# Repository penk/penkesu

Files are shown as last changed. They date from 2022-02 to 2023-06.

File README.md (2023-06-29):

# Penkesu Computer - A Homebrew Retro-style Handheld PC



The Penkēsu (Japanese: `ペンケース`) is a retro-style handheld device powered by a Raspberry Pi Zero 2 W, a 7.9 inch widescreen display (1280 x 400 resolution), and a 48-key ortholinear mechanical keyboard. 

## The Design

The enclosure of the Penkesu Computer is designed around the display and keyboard to ensure (relatively) compact physical dimensions.

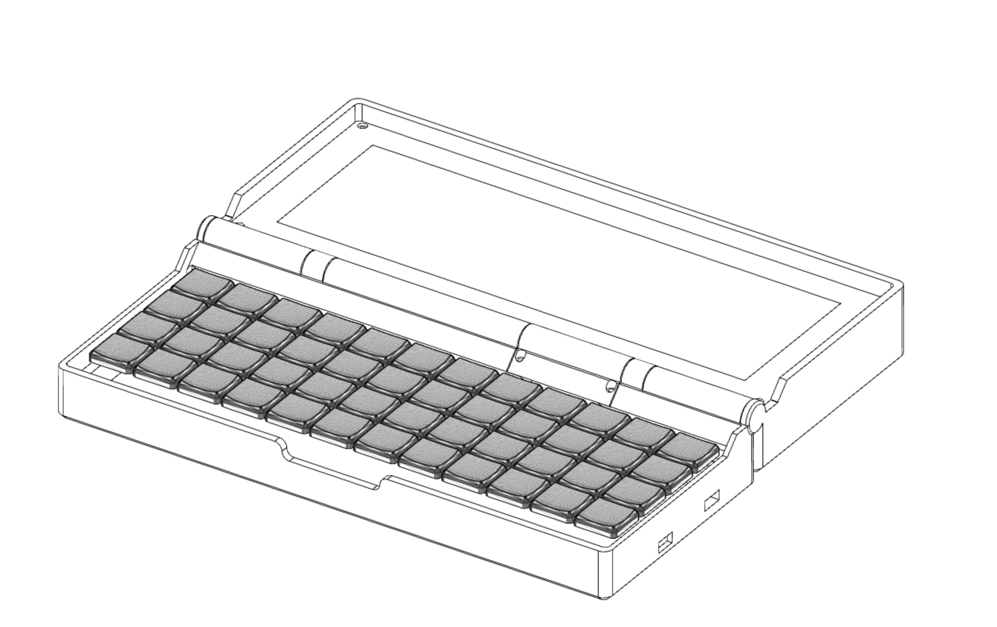
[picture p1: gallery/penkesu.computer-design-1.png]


Repurposed Gameboy Advance SP hinges and a ribbon cable for HDMI are used to keep the hinge design thin, yet they hold the weight of the display so that it won't tip over.

Electronics are intentionally kept minimal (3 internal components) and most of the parts are either 3D printable or available as off-the-shelf products. 

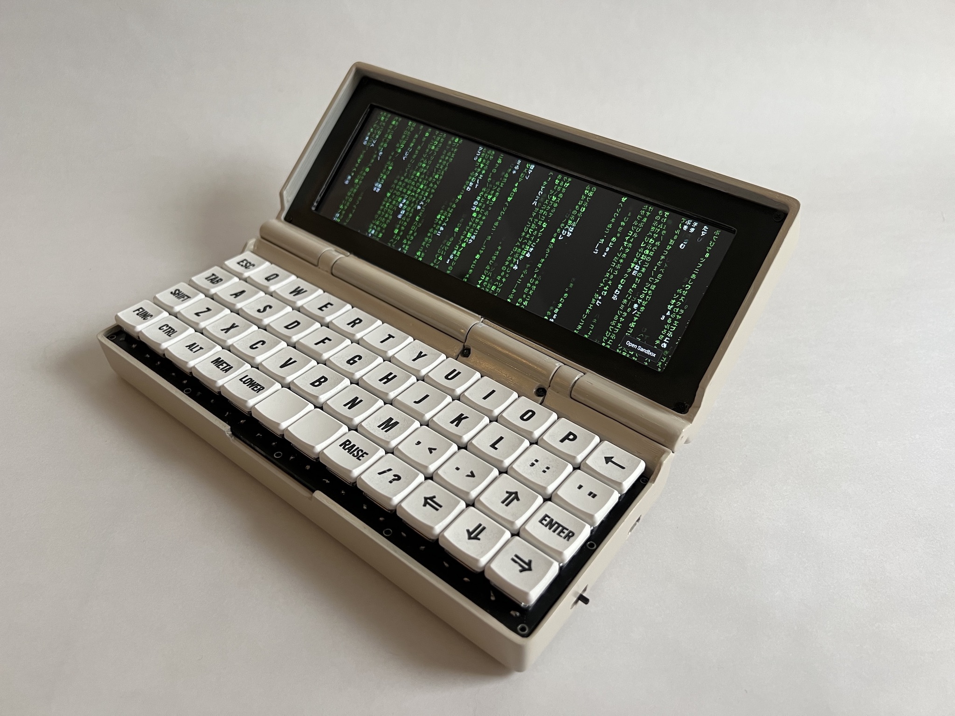
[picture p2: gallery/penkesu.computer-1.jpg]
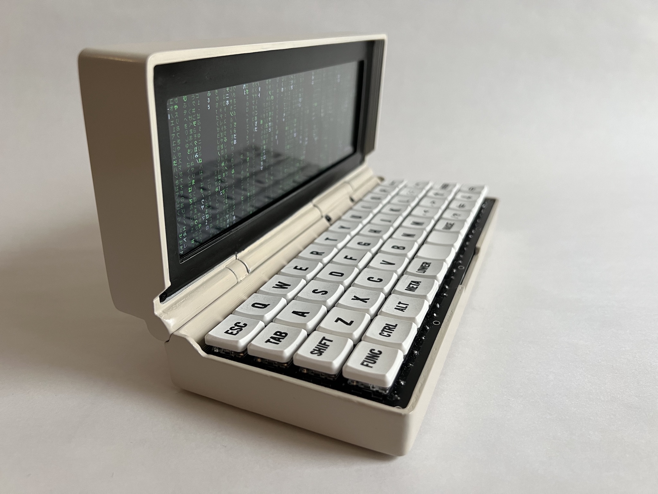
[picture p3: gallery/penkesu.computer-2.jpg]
|  |  | 
|---|---|
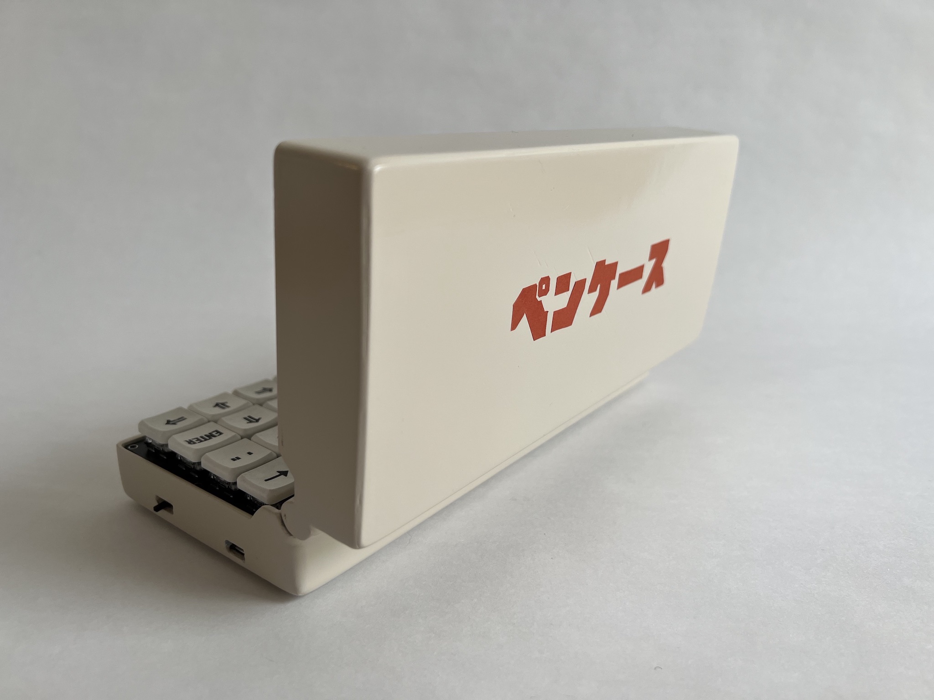
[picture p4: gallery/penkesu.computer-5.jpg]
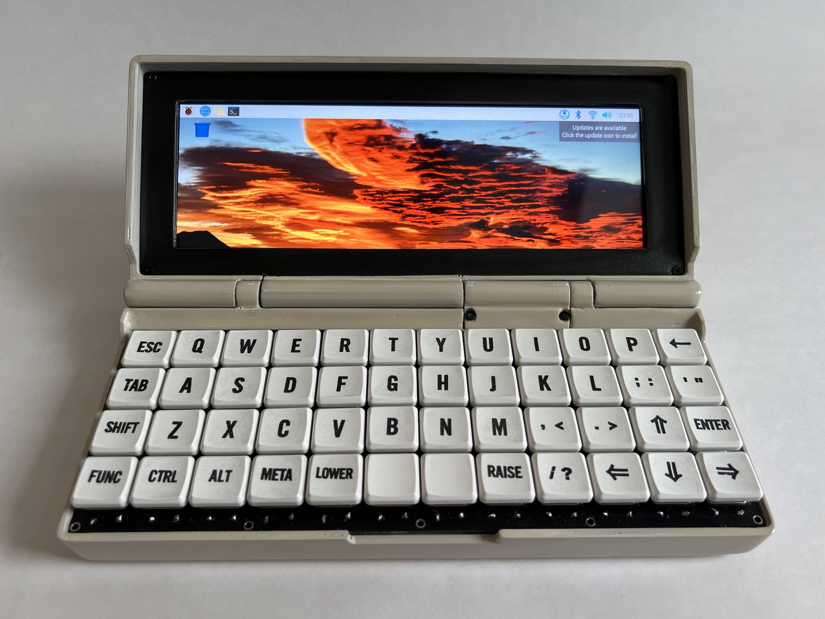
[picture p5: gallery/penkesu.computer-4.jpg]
|  |  | 
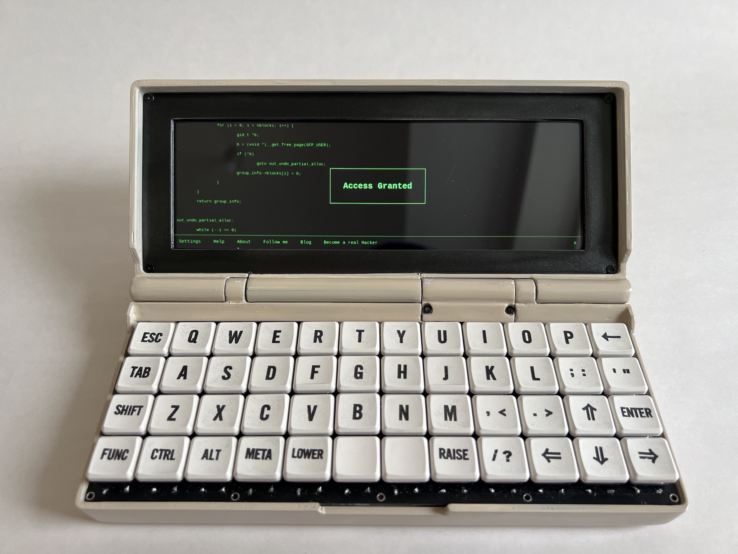
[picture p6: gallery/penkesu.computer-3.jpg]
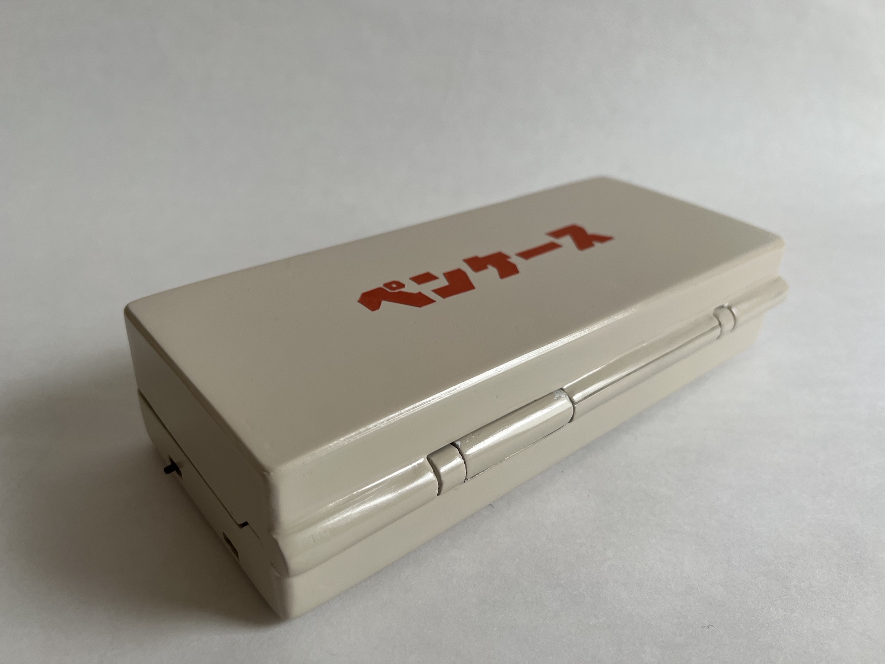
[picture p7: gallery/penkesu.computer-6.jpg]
|  |  | 

See also: the keyboard [sound test video](https://twitter.com/penk/status/1492715339997925376).

## Open Source Hardware 

Ever since the [CutiePi tablet](https://cutiepi.io) was successfully funded and started shipping, I felt the need to work on a new project; something that I didn't need to worry too much about (ie: commercial viability), and to remind myself why I started tinkering. A "rebound" project, so to speak. 

And since there are no immediate plans on selling kits or making the Penkesu Computer mass producible, I wanted to publish all the designs and plans so there's enough information for anyone interested in making one. 

## Bill of Materials 



- Display 
    - Waveshare [7.9inch Capacitive Touch Screen](https://www.waveshare.com/7.9inch-HDMI-LCD.htm)
    - Adafruit DIY HDMI Cable Parts - [Right Angle adapter](https://www.adafruit.com/product/3550), [Mini HDMI adapter](https://www.adafruit.com/product/3552), and [20cm Ribbon Cable](https://www.adafruit.com/product/3561)
- Case 
    - Gameboy Advance SP [Replacement Hinges](https://amazon.com/dp/B00YCEOXIK)
    - 3D printed parts ([STL files](stl) and [STEP file](step)) 
    - M2x6mm screws x 6 (8 if intending to secure the keyboard to the bottom tray. See part 2 below for more info.)
    - M2x6mm threaded heat-set inserts x 6 (8 if intending to secure the keyboard to the bottom tray. See part 2 below for more info.)
- Electronics 
    - Raspberry Pi [Zero 2 W](https://www.raspberrypi.com/products/raspberry-pi-zero-2-w/)
    - 3.7V 606090 (or similar size) [Li-Po battery](https://www.aliexpress.com/wholesale?SearchText=606090+battery)
    - Adafruit [PowerBoost 1000C](https://www.adafruit.com/product/2465)
- Keyboard 
    - Kailh Low Profile [Choc v1](https://www.adafruit.com/product/5114) Switches x 48
    - MBK Choc Low Profile Keycaps x 48
    - 1N4148 Diode x 48 
    - Arduino Pro Micro x 1
    - PCB x 1 ([gerber file](https://github.com/larrbo/odd-rocket/blob/master/koda/koda_no%20silk.zip) and [QMK firmware](firmware))

Links are **not** affiliate links, and only provided as references. 

## Notes on the Keyboard

About the keyboard: 

- The keyboard is called `Koda`, which is originally designed by [larrbo](https://github.com/larrbo/odd-rocket/) and released under Creative Commons BY-NC-SA 4.0 License. I've tweaked the layout so that it better fits my needs and looks closer to the `Planck`. More on this below.
- If one wishes to use a different 40% keyboard for the build, it can be done by editing the STEP file and adjusting the compartment size in the chassis.
- A thin metal sheet was [glued to the base](https://twitter.com/penk/status/1489810591628034048) as the counterweight, your mileage may vary depending on how you like the weight distribution

For the keycaps: 

- The legends on keycaps were [printed with a laser engraver](https://twitter.com/penk/status/1477140916565843968), which I used [black dip powder for nails](https://twitter.com/penk/status/1475763655212138499) as pigment. 
- More information about this method can be found with keywords [laser dye-sub keycaps](https://www.youtube.com/watch?v=qqAspFVRZNk) 
- There are custom printing services for keycaps e.g. [yushakobo.jp](https://shop.yushakobo.jp/collections/services/products/keycap-laser-marking) if one does not have access to a laser engraver.

Keyboard Layout: 



The lower key activates a layer that primarily has number keys from ` to 1 - 0 across the top row (excluding the top right key, which is the backspace key in all layers). 
The raise key activates a layer that has the shifted version of all of the numeral keys from the lower layer. As well as function keys using the tab,a,s,d,f,g and shift,z,x,c,v,b keys for F1-F6 and F7-F12 accordingly. 
Pushing func key down and holding it activates a mouse layer. The mouse layer uses an accelerated mode but allows one to temporarily activate the constant mode using an additional key. As you  might have guessed, when using the accelerated mode the speed of the cursor is initially slow but over time increases in speed. This mode is active as soon as mouse mode is entered. (by holding down the func key) Your w,a,s,d keys are you cursor movement keys. Your left, right, and middle mouse buttons are j,k, and l respectively. Your scroll wheel uses the t,f,g,h keys. Finally mouse cursor speed can be toggled by tapping or by holding. If tapped the keys change the speed of acceleration. If the keys are held they will activate constant mode at the equivalent mousing speed.  There are 3 overall speeds: 0, 1, and 2, with 0 being the slowest and most precise, and 2 being the fasted and most inaccurate. You access speed 0 using the v key. Speed 1 using the b key. And the fastest speed (2) using the n key. 

## The Assembly 

1. Glue the two hinges to the chassis (my 3D printer is not accurate enough to print a functional hinge lock, so I simply glued them with 5 minute epoxy.) You want to make sure that the hinge is able to still turn after the epoxy has set. 

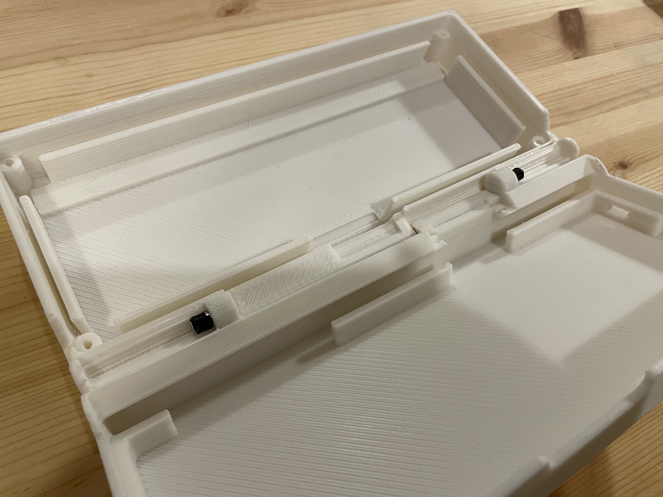
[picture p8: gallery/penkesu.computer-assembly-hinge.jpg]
  

2. Add heat-set threaded inserts (M2x6mm) to the 4 corners of screen bezel, and 2 to the hinge cover. You may also use heat insert at the front corners of the keyboard tray. Just note that placing these inserts are very difficult, and not entirely necessary. For ease of access you may wish to not use them at all. 

3. Wrap the ribbon cable twice and pull it out through the hinge cover. If you use a toothpick, it might make it easier to ensure you do this cleanly through the display cover. 

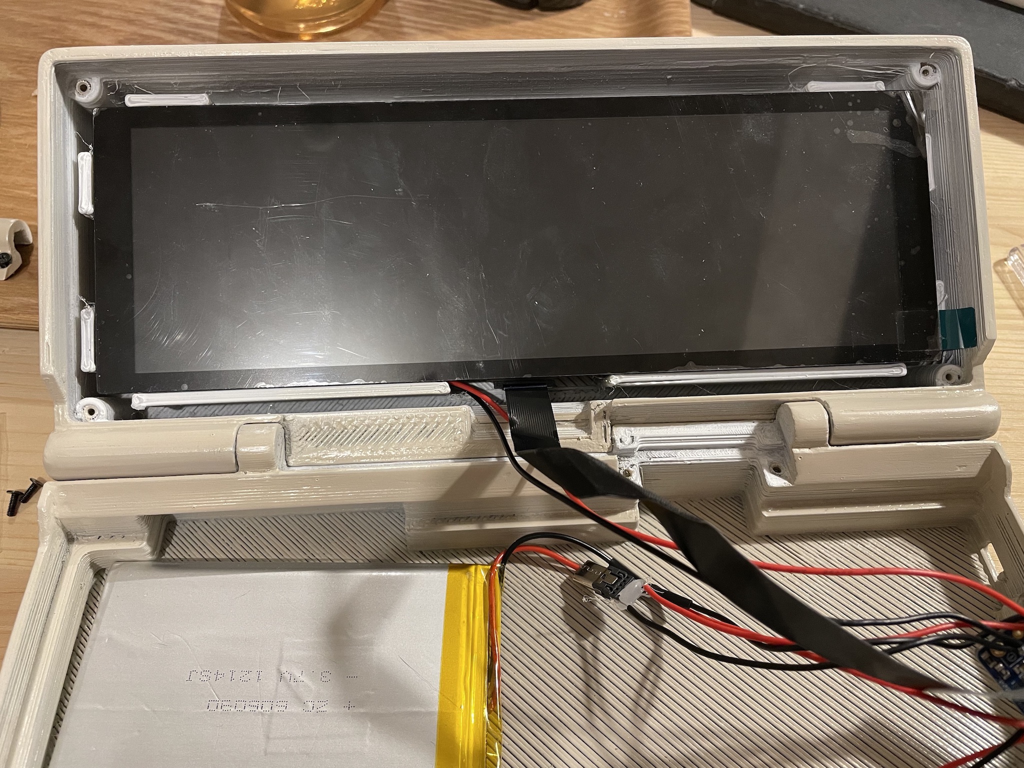
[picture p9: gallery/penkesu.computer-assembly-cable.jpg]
  

4. Wiring: 

    | Component | Pin | 
    |-----------|--------|
    | battery positive | PowerBoost `Bat` pin |
    | battery negative | PowerBoost `GND` pin | 
    | switch 1 pin | PowerBoost `GND` pin | 
    | switch 2 pin | PowerBoost `EN` pin | 
    | PowerBoost `5V OUT` | display and Pi Zero's `VCC` | 
    | PowerBoost `GND` | display and Pi Zero's `GND` |

     

5. Connect the keyboard's micro USB and the display cable into the mini HDMI port of the Pi Zero 2 W; inset the micro SD card into the Pi Zero 2 W. 
6. Fasten all components with M2x6mm screws. 

If you made it this far, you are welcome to check out my other project, [the CutiePi tablet](http://cutiepi.io), which is also 100% open source hardware! :-)

## Copyright and License

Copyright (c) 2022 Penk Chen. All rights reserved.

All files are licensed under MIT license, see the [LICENSE](LICENSE) for more information.

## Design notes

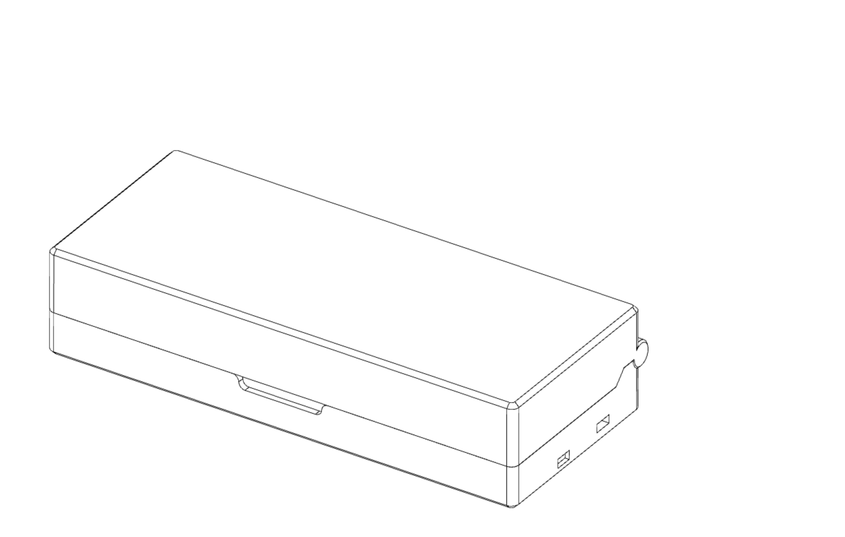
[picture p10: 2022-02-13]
gallery/penkesu.computer-design-2.png

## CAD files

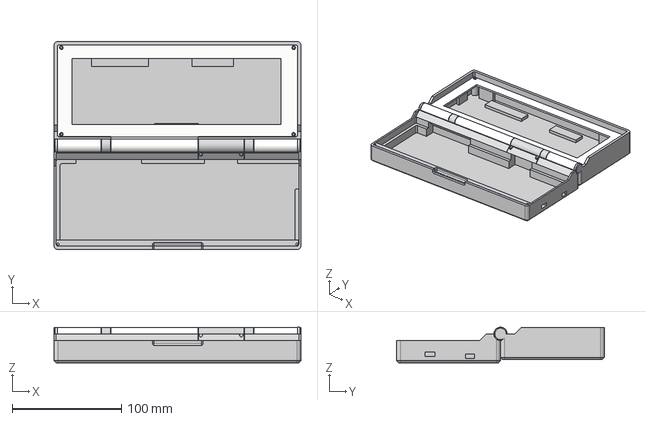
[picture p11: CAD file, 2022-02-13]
step/penkesu.computer-chassis.step
225.6 x 189.9 x 32.6 mm
penkesu-chassis_1
penkesu-screen

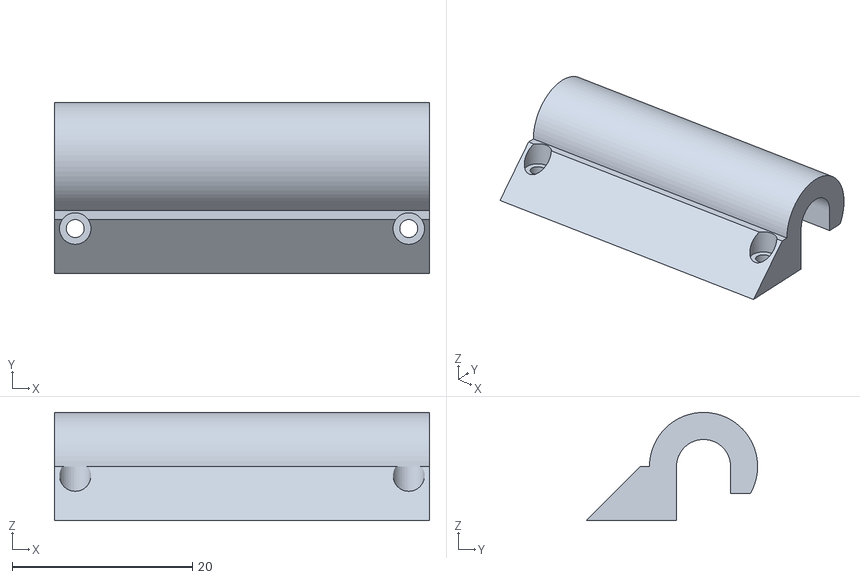
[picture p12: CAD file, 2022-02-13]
stl/penkesu-hinge-cover-mid.stl
41.6 x 19.0 x 12.0

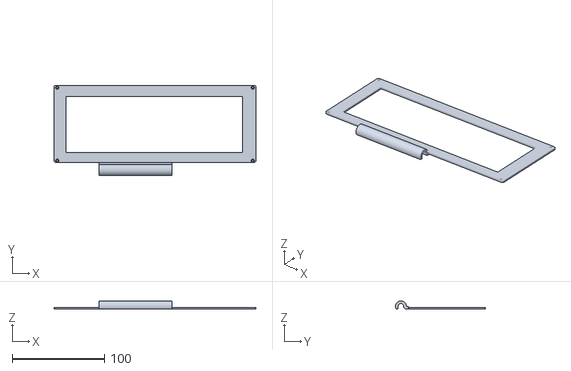
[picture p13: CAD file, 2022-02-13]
stl/penkesu-screen-panel.stl
219.2 x 97.8 x 8.99

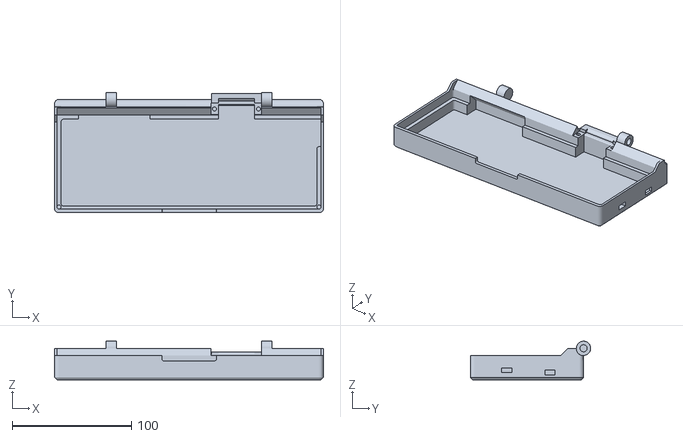
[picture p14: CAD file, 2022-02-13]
stl/penkesu-chassis.stl
225.6 x 101.0 x 32.5

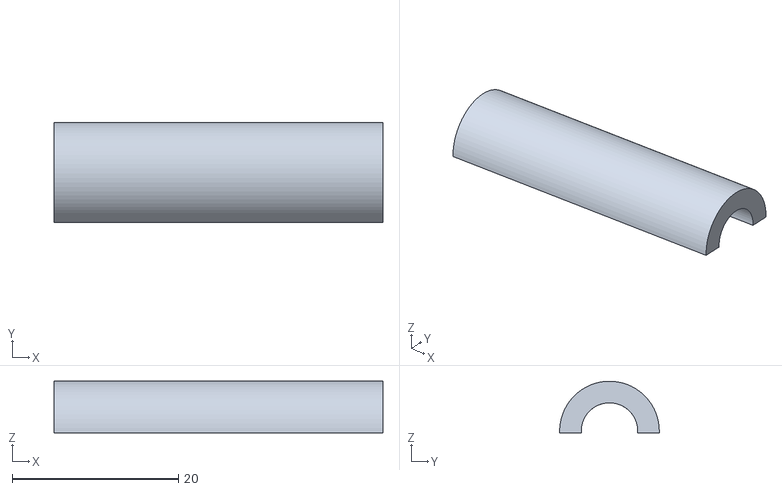
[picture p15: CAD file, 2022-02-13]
stl/penkesu-hinge-cover-right.stl
39.6 x 12.0 x 6.20

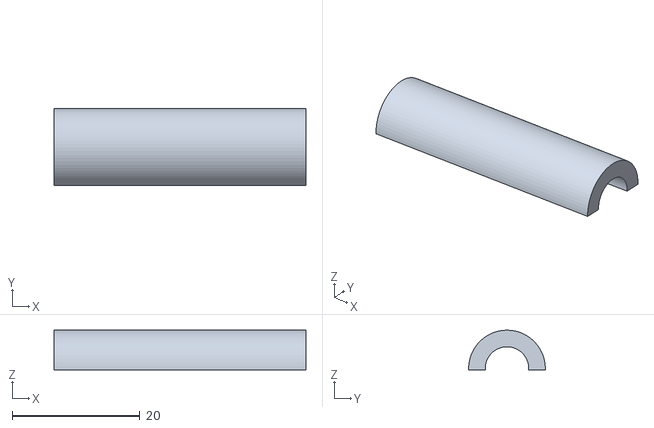
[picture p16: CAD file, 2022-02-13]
stl/penkesu-hinge-cover-left.stl
39.4 x 12.0 x 6.20

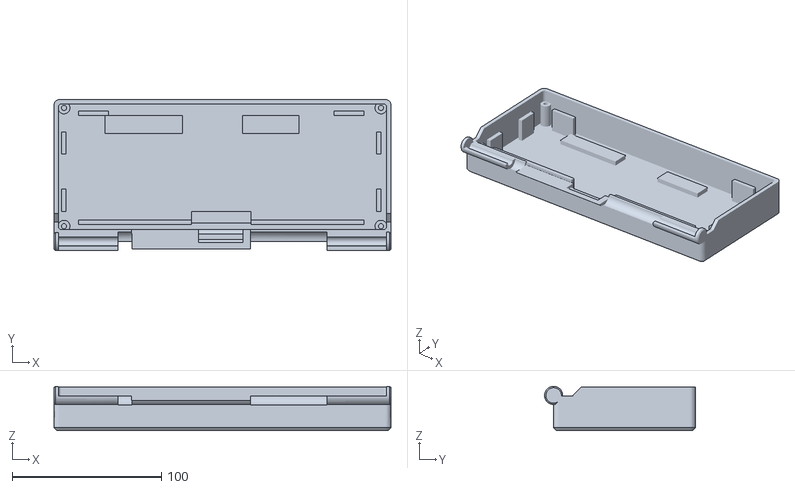
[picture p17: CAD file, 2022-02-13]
stl/penkesu-screen-case.stl
225.6 x 101.0 x 29.7

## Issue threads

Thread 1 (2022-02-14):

design enclosure

wir19, 2022-02-14:
0. Please look at old Psion 5 keyboard and hiding it under screen.

1. In my opinion second idea are waterproof box enclosure similar normal army box.

2. is possible add some keys near screen? turn off wifi, decrease speed cpu, speed memory etc.

meybe add solar panel on top for increase working time?

penk, 2022-02-14:
@wir19 thank you for your suggestions, this is an open source project, so please feel free to modify the design and make it yours. :-)

Closed 2022-02-14.

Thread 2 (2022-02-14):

Os

gedw99, 2022-02-14:
You got slash dotted !

https://www.tomshardware.com/news/raspberry-pi-zero-2-w-penkesu-computer

Have you decided on an OS ?

gokrazy might be a good fit for super low resource device . I run it

https://github.com/gokrazy

for apps you can use Fyne or gioui

https://github.com/fyne-io/fyne

https://github.com/gioui

I use gio cause it’s gives the most flexibility. It would not be hard to get it running with gio and the community would probably help you ! They are pro open source .

This makes it very lean and easy for you and others to build apps for it .

gedw99, 2022-02-14:
Also AdGuard ad blocker is programmed in go so if you wanted to add a web browser it would be relatively easy to integrate AdGuard into it .

gioui is similar to QT but

gedw99, 2022-02-14:
https://gokrazy.org/platforms/#raspberry-pi-zero-2-w-work-in-progress

penk, 2022-02-14:
@gedw99 thank you for your comments! Right now we are using Raspberry Pi OS Bullseye since it's working out-of-the-box.

(btw I'm one of the author of cutiepi-shell so I'm flattered ;-)

gedw99, 2022-02-15:
no worries.

gedw99, 2022-02-15:
@penk when can i get my hands on the hardware ?

Closed 2022-02-14.

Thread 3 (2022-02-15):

Which Arduino Pro Micro did you use?

RicInNewMexico, 2022-02-15:
May seem like kind of an odd question.. but which specific pro micro did you go with? I'm familiar with the pro micro (RP2040 I think..) sold by SparkFun, but they've been out of stock and backordered for a while.

RicInNewMexico, 2022-02-15:
Nevermind! Realized I can likely use an Elite-C from Boardsource

Closed 2022-02-15.

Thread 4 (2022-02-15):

Support Radxa Zero

hipboi, 2022-02-15:
Raspberry Pi Zero 2 W ram is only 512MB, which is not enough for desktop usage. Could you support [Radxa Zero](https://wiki.radxa.com/Zero) 4GB ram model?

penk, 2022-02-15:
That looks cool, do you know how do I get one?

Drizzt321, 2022-02-15:
That's interesting. The [buy page](https://wiki.radxa.com/Buy) shows [Seeed](https://www.seeedstudio.com/ROCK-Pi-4-c-1323.html). Don't see it there though, strangely. Does seem to be on [ALLNET China](https://shop.allnetchina.cn/collections/frontpage/products/copy-of-radxa-zero) though, and also includes options for up to 128GB eMMC which seems quite interesting. Not all that pricey for that, although not sure on shipping.

Still supports mSD cards, and USB-C instead of micro-B for power & data, and micro HDMI connector vs mini HDMI on the RPi Zero 2W. So still pretty standard, but probably needing slightly different cables/adapters. I haven't looked close, but the 40-pin header I bet is compatible.

hipboi, 2022-02-16:
@penk  We can just ship one free sample to you. Please [send me](mailto:tom@radxa.com) your shipping address.

RicInNewMexico, 2022-02-16:
> @penk We can just ship one free sample to you. Please [send me](mailto:tom@radxa.com) your shipping address.

Now that's community support! I was just going to comment and list which distributors carry the Radxa Zero.. just ordered a 4GB ram / 32GB eMMC for my penkesu build last night

cristicbz, 2022-04-08:
@hipboi I tried to get this to work for a couple of evenings, but wasn't able to get the screen to work. Tried a custom modeline, kernel params, but no luck. Seems like the modesetting driver doesn't support the odd resolution (400x1280)?

Someone else also struggled by looks of it: https://forum.radxa.com/t/waveshare-7-9in-touchscreen-support/7555

I'm by no means an expert, so I'm sure someone else could make it work. Might need a kernel patch

hipboi, 2022-04-17:
@cristicbz somehow I missed this thread, @RadxaYuntian will follow up this issue. I believe we need some custom edid for this panel.

markcordova, 2022-05-22:
@hipboi this issue is now closed, does this mean that the radxa zero is tested to be working fine in this setup? thanks

2disbetter, 2022-05-22:
@markcordova unfortunately a radxa Zero was not available. Instead of leaving the issue open and hanging, it is just closed until one can be attained. I personally think a Radxa would be excellent in there. I'm a little worried about clearances, but it should be fine.

Drizzt321, 2022-05-24:
@2disbetter I got my hands on a Radxa Zero, haven't done anything yet. I can lend it to you to do the testing you need, and then send it back.

2disbetter, 2022-06-10:
Thanks Drizzt, I was able to get one too. I'm tinkering with it now. Just trying to get the waveshare display to work. I really want to check the power requirements and see how the thermals are. Will post again when I have something to report.

kariudo, 2022-06-10:
> Thanks Drizzt, I was able to get one too. I'm tinkering with it now. Just trying to get the waveshare display to work. I really want to check the power requirements and see how the thermals are. Will post again when I have something to report.

Should probably re-open the issue, if its in progress. I'd be interested in this too, especially with hardware shortages for things like zero w 2.

2disbetter, 2022-06-10:
right now the display not working is the main issue. Still working on it, but would be very happy if we could get a comment from hipboi about the driver and the waveshare screen used with the Penkesu.

jcbergerson, 2022-07-24:
I also am curious about the radxa Zero/Zero 2 @hipboi for the penkesu platform. The video driver and support of the waveshare screen would be awesome! The future collaboration of the open @penk pocketPC and the possibilities of the Radxa Zero platform as it’s heartbeat would be cutting edge magical!

RadxaYuntian, 2022-07-25:
So the preliminary investigation shows this is likely a driver issue. The resolution for the screen is actually 400x1280 as that's the default display orientation. In meson driver, there are [predefined resolutions](https://github.com/analogdevicesinc/linux/blob/a34dd103e47072bad06d513e356b2cf5df0f71c4/drivers/gpu/drm/meson/meson_venc.c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) and custom resolutions. Any custom resolutions with horizontal resolution less than 640, or vertical resolution greater than 1200 [is rejected](https://github.com/analogdevicesinc/linux/blob/master/drivers/gpu/drm/meson/meson_venc.c#L869=) by the driver.

We might be able to add a custom resolution in the predefined list. Will need more investigation to solve this issue.

2disbetter, 2022-11-28:
> We might be able to add a custom resolution in the predefined list. Will need more investigation to solve this issue.

Any luck on this? I have since been able to source a battery charger that can output 5v at a max of 3A. I would really love to try the Radxa with a USB hub and see if I can get the display and the touchscreen working. It would be one significant upgrade to the Penkesu.

RadxaYuntian, 2022-11-29:
The driver limitation [was lifted](https://github.com/radxa/kernel/pull/26) so display should work now. The touch screen IIRC is USB based? In that case it should work as well.

2disbetter, 2023-05-09:
Thank you, we will work on adding this to the build. This would represent a significant bump in performance.

markcordova, 2023-06-07:
@2disbetter I can confirm that the display now works with the Radxa Zero, and with a USB hub the touchscreen works as well.

Closed 2023-05-09.

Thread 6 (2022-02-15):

External USB and/or UART ports

Drizzt321, 2022-02-15:
Any thought to bringing out UART (maybe from an FTDI?) or USB hub to allow for external USB connections as well? I imagine this could be a very handy micro computer to carry around to be able to flash/reprogram/debug IoT/micro stuffs.

Something like [this USB + Ethernet](https://www.adafruit.com/product/2992) could be quite handy to have. Pull the case off and mount it bare PCB internally. Or perhaps [this one](https://www.amazon.com/Cable-Matters-Ultra-Mini-Port/dp/B00PHPWLPA) is better, since it could go in a corner and provide 2 external USB, and 2 internal USB while still giving USB3.0 speeds.

Or actually [this adafruit board](https://www.adafruit.com/product/3298) is interesting, and it uses pogo-pins to 'takeover' the USB header output. At least of the Zero/Zero W, not sure on the Zero 2 W.

2disbetter, 2022-04-24:
In the current design there isn't enough room for the pogo-pins board height wise. I'm currently experimenting with a retrocution mini usb hub. If I can get it to work, what you're asking here should be possible. The biggest concern for right now is available power. The Zero and display use about .8A of the available power. This leaves only .2A to use. This limits the amount of things you could connect. Still, I'm hoping to at least be able to use a USB thumb drive, etc.

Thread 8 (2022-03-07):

Re: PCB for Keyboard

michaeldvinci, 2022-03-07:
This project is really cool, props!

I was wondering if you could flush out the README with more info as to how to order a version of the keyboard PCB? I've never tried ordering PCBs before and had no luck trying to find a fiscal way of getting it done. The only websites I could find to print custom PCBs wanted ~$60 to print 1x piece, so I was hoping maybe you had some good info on cheaper/decent pricing for ordering?

If there's a better place for this just let me know!

cristicbz, 2022-04-08:
In the EU [Aisler](https://aisler.net/) makes reasonably priced boards, in the US people will typically pick [Oshpark](https://oshpark.com/) though I have no experience with them.

Generally, if you want cheap boards you have to with Chinese manufacturers and pay a bit more on shipping (assuming you're not in China). I used JLCPCB, uploaded gerber files, picked black soldermask, 1.6mm FR4, HASL Lead-free, and got some beautiful boards for ~$30 for 5 pcb-s including shipping.

For the actual assembly I found the blogpost that is ultimately linked form the readme (if you jump through a few links) very helpful: https://oddrocketkeyboards.blogspot.com/2018/05/koda-keyboard-4x12-grid-using-kailh-lp.html

See PCB and assembled board:
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

Closed 2022-04-24.

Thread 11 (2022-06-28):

Keyboard connection

gopher333, 2022-06-28:
Hi, I would appreciate a little more detail about the hardware configuration of the keyboard. How do I attach the Arduino Mini to the Keyboard (Pin Numbers)? I suppose the USB Port has to be to the outside of the PCB, but in which direction? USB side to the PCB or away from it? A picture would do...also the connection of the 4-pin usb connector would be helpfull (PINS?)
Tks is advance?

2disbetter, 2022-06-28:
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
The micro usb port goes facing the Keyboard PCB. This picture should show you the pins. Be careful that nothing is touching metal on metal there. I actually put a small piece of kapton tape in between just to make sure.

gopher333, 2022-06-29:
Thanks a lot for thte immediate answer, that does it!

Closed 2022-06-29.

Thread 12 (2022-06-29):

Touch Display usable?

gopher333, 2022-06-29:
Dear Penk, my Penkesu is now almost finished! Thanks for the work, and most for sharing it! Just a question; As far as the used display is a touch display, is there any argument against using it that way? There is still an usb Port on the RasPi available...

cap-steve, 2022-12-12:
wondering if this ever got tested.
i've been looking at various usb hats and wonder if it's worthwhile to pursue, even at the expense of battery life.

markcordova, 2023-06-16:
I use an internal 4-port USB hub to connect the touchscreen and the keyboard (search for fe1.1s USB hub if interested).

2disbetter, 2023-09-27:
> I use an internal 4-port USB hub to connect the touchscreen and the keyboard (search for fe1.1s USB hub if interested).

Could you share a picture of how you have it configured internally on your Penkesu? Is power supply sufficient?

Steuv1871, 2024-03-02:
Hey ! I got the touchscreen to work with a usb hub + OTG adapter on Pi Zero mini USB.
I'm using a [pi-juice zero hat](https://uk.pi-supply.com/products/pijuice-zero) and it supply enought power.
More than that, the display don't work unless I plug the usb cable (power over hdmi is not enought).

It's a bit difficult to touch things too close from the border due to the screen panel thickness. But it's usable enought for desktop WM like xfce.

But be carefull with the pi-juice zero hat, it's too thick for the Penkesu original design, I had to modify the STLs.

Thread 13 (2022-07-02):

Keyboard Install

gopher333, 2022-07-02:
Dear Penk, for your Keyboard Hex File-what Keyboard software installation did you use in Bullseye? I am from germany, tried the Keyboard on my windows Computer (works), but the keys have different values then.

2disbetter, 2022-07-06:
Hi again, I used the QMK Toolbox to flash the board. You me3rely grab that open it open, and then while sorting a pin on the board to enter flashing mode on the board, you connect it via USB. The Toolbox will find it and install the firmware.

Closed 2022-07-26.

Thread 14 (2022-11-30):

Booting directly to cool-retro-term console

Kingeorg, 2022-11-30:
Hello.
-1st. I must thank you for your project and the inspiration provided, I was looking for a portable terminal and this is the perfect size.
-2nd. I successfully completed my Penkesu! It works perfectly, albeit with some modifications (using instead a 30% gherkin keyboard) and a custom made LEGO case, it is beautiful!
-3rd. Here's my question. How can I boot directly into cool-retro-terminal (the terminal emulator you use with your Main Board Terminal project)? I know this is a software issue, but I figured you would know as you referr to it in your other project. Hardware-wise, the Raspberry Pi Zero 2W I'm using does run cool-retro-term at a decent speed when you adjust the performance from within the program, my issue is that I'd like to run it as closest to "bare metal" as possible, with the minimum requirements, and directly as possible. I managed to boot to cool-retro-term but only after the Raspbian desktop environment loads (it takes a while and the transition is ugly). Unfortunately cool-retro-term seems to need some kind of Window Manager, so It cannot boot directly from the terminal before the desktop environment starts. I tried loading have spent a lot of time trying to figure it out, whitout getting good results. What do you suggest?

penk, 2022-12-05:
Hi @Kingeorg thank you for the ticket, that's awesome! If you have any pictures of your build please do let me know, would love to see it! :-)

For booting directly into cool retro term, I think the easiest way is to add an `.desktop` file under `/etc/xdg/autostart` so it'll launch automatically when the desktop starts -- it is heavier (with Xorg and mutter window manager and other layers).

There's another way you can probably try, stop your Xorg with `systemctl stop lightdm` and starting cool-retro-term with `-platform eglfs` parameter, I haven't tested this but it should work without any display server or window manager.
Let me know how it goes, you'll probably have to grand your user account with permission to draw directly:

```
sudo gpasswd -a pi render
sudo gpasswd -a pi dialout
sudo gpasswd -a pi input
```

You can find more info about EGLFS here: https://doc.qt.io/qt-5/embedded-linux.html#eglfs

Let me know how it goes!

Kingeorg, 2023-01-13:
Thank you. I'll give it a try now that I have time and let you know how it goes.
In the meantime, I'd like to share what I made inspired by your Penkesu project:
https://www.reddit.com/r/cyberDeck/comments/zfbioy/my_wallnut_lego_cyberdeck/

2disbetter, 2023-04-30:
Seems solution was given, or a possible, and as such closing this one. Thanks!

Closed 2023-04-30.

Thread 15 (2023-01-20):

More details for assembling PCB - diode and chip orientation, location?

CJ-eng, 2023-01-20:
Hi Penk,

Excellent project, I am in the process of assembling one. As I have not assemble a mechanical keyboard before, I wonder if you could provide more details on making the PCB. I am assuming the diode and the Pro Micro goes on the bottom side of PCB where as the key switch goes on the top side. Where does the diode goes exactly? And when soldering the Pro Micro, what’s the orientation? Would you provide a simple illustration or diagram? Thanks in advance.

penk, 2023-01-20:
Hi @CJ-eng thanks for your interest in the project, for the build log I'd refer you to koda keyboard's creator and author :-)

Hope this helps:
https://oddrocketkeyboards.blogspot.com/2018/05/koda-keyboard-4x12-grid-using-kailh-lp.html

Closed 2023-01-20.

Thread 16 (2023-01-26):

Need help to rotate the screen

CJ-eng, 2023-01-26:
Hi Penk,

I've hooked up everything minus the keyboard (still waiting for PCB). However, for testing purpose, I hook up regular keyboard to Pi Zero's USB port. So everything works nicely except the default Waveshare screen is vertical. I edit the config.txt file as per Waveshare's Wiki page but it is not working :-(

Please let me know how to get the screen to rotate. Thanks!!!

penk, 2023-01-26:
For the record it was set with xrandr commands. :-)

CJ-eng, 2023-01-26:
Thanks for your reply. I have to delete everything else in the config.txt file and then the rotate command works. But I will try your command as well. I am enjoying the pencil case PC very much!

Closed 2023-01-26.

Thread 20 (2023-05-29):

Parts list doesn't mention the m2 screws

jedicobra, 2023-05-29:

2disbetter, 2023-06-07:
Thanks for adding this to the parts list!

Closed 2023-06-07.

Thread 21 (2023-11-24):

Chocfox keycaps viability and stabilizers

warningboatheli, 2023-11-24:
Hi Penk! I came across the [ChocFox CFX BoW keycaps](https://chosfox.com/products/cfx-bow?variant=43187789988034) and was wondering if these would be viable in the Penkesu. They're 16.5 mm square whereas the MBKs are 17.5mm (horizontal) x 16.5mm (vertical). I don't want to ruin the aesthetic with big gaps, so I'm hoping the extra .5 mm wouldn't be atrocious?

Also, they weren't listed in your list of materials so I'm assuming you didn't use them, but I was wondering if you do or don't recommend adding stabilizers.

TIA! This is my first ever build, probably a little ambitious, but it's something I'm really excited to make!

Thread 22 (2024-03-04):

Original design files?

pterodyne, 2024-03-04:
Probably too much to ask, but Im using this as a basis for a larger design for a 10.1" DSI display and a PI5.  Ive been slicing and dicing the STL files in tinkercad, trying to keep all dimensions the same (hinges/bezels etc), and only inserting space along the xy axis by cutting and then extruding a center part.  It's working well enough.  But If the original files were available in fusion, freecad or whatever was used that would make it easier.  The STEP files possibly could be used and look great, but I think it would be easier to adjust the constraints only in the places I need. Probably what I have would work fine if not. Just thought it might be worth asking.

Thanks again for a great project!.

Bryan

pterodyne, 2024-03-04:
Oh and Ill be using a vortex core keyboard and an MNT Trackball if anyone was wondering.  Should make a nice little (and fairly useable) retro laptop.

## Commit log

2022-02-13 Add STEP file
    [penkesu.computer-chassis.step]
2022-02-13 Add 3D model
    [penkesu-chassis.stl, penkesu-hinge-cover-left.stl, penkesu-hinge-cover-mid.stl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]
2022-04-20 Add files via upload
    Updated keyboard firmware that adds a mouse layer in the place of the function key. By holding down the function key (bottom left hand key) you activate mouse mouse mode. This will make wasd your cur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
    Another note is that the raise key while giving you access to special characters will now also give you access to F1-F12. The keys for this are qwerty and asdfgh respectively.
2023-05-24 Added screws to parts list
